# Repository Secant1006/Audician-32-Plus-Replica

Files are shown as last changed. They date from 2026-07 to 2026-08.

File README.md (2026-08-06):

# Audician 32 Plus Replica

This is a reverse-engineered sound card based on [Labway A151-A00](https://theretroweb.com/expansioncards/s/labway-corporation-labsound-a00-ide-power-a), which is a Yamaha OPL3-SAx based sound card. The OPL3-SAx is a single solution sound chip which provides Sound Blaster Pro 2.0 and Windows Sound System compatibility, and more importantly, a genuine OPL3 FM synthesizer. It's almost perfect (except ADPCM support) for PC-based retro gaming. Besides outstanding compatibility, this card is also noise-free and has acceptable frequency response.

As of August 2026, no one has published any schematic for this chip yet. This project aims to provide a reverse-engineered schematic and nearly 1:1 clone of the A151-A00 sound card with some modifications:

* Wavetable reverse channel bug is fixed
* Original FCC ID and CE logo are not used
* Silkscreen font is different
* Footprints are replaced with KiCad defaults plus some self-made ones
* Silkscreens for chip model are corrected
* Board is slightly longer and the ISA connector is moved slightly to comply with ISA standard

One configuration of the board is manufactured and validated to work perfectly fine.

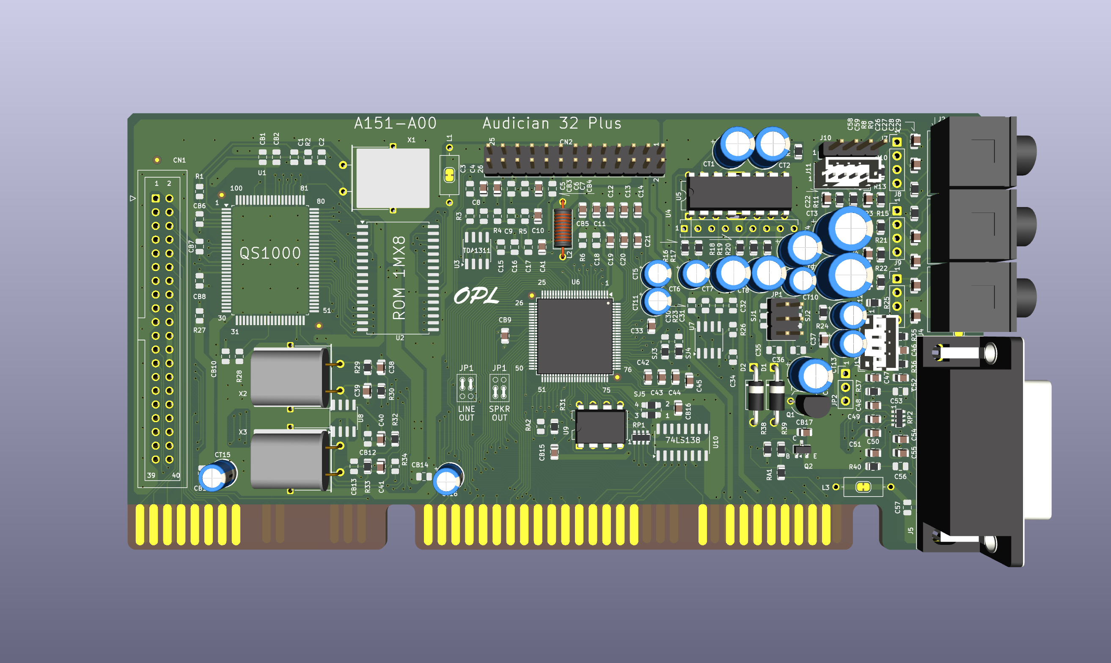
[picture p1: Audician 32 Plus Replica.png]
PCB Rendering


# Project Structure

* `bom/`: Interactive BOM
* `eeprom/`: EEPROM dump
* `gerber/`: Gerber files for the PCB
* `jlcpcb/`: JLCPCB production files
* `references/`: Reference documents, including datasheets for chips, ISA standard specification and photos of the original PCB
* Others: KiCad project files

# BOM

| References | Value | LCSC Part Number |
| --- | --- | --- |
| C4, C7 | 150pF 0805 | C1716 |
| C5, C10 | 220nF 0805 | C5378 |
| C11<sup>[1]</sup>, C12<sup>[1]</sup>, C19<sup>[1]</sup>, C20<sup>[1]</sup>, C44, C45 | 1nF 0805 | C46653 |
| C13, C21, C48, C49, C50, C51 | 10nF 0805 | C1710 |
| C14, C33, C37, CB5, CB9, CB15, CB16, CB17 | 100nF 0805 | C49678 |
| C22, C23, C24, C25, C28, C42, C43, C46 | 1uF 0805 | C28323 |
| C26, C27 | 470pF 0805 | C1743 |
| C29, CA1 | 100pF 0805 | C1790 |
| C38<sup>[2]</sup>, C39<sup>[2]</sup> | 4.7pF 0805 | C1820 |
| C40, C41 | 22pF 0805 | C1804 |
| C47, C52, C54, C55, C58, C59 | 47pF 0805 | C14857 |
| CT1, CT2, CT4, CT7, CT8 | 100uF D6.3xL7 | C106447 |
| CT3, CT10 | 470uF D8xL11 | C106735 |
| CT5, CT11 | 22uF D5xL7 | C112508 |
| CT6, CT9, CT12, CT13, CT15, CT16 | 10uF D4xL7 | C5123345 |
| CT14 | 100uF D6.3xL7 | C2826426 |
| R7, R18 | 510Ω 0805 | C17734 |
| R8, R9 | 47kΩ 0805 | C17713 |
| R10, R11, R12, R13 | 20kΩ 0805 | C4328 |
| R14, R21, R35 | 220kΩ 0805 | C17556 |
| R15, R22, R36 | 33kΩ 0805 | C17633 |
| R16, R17, R19, R20 | 27kΩ 0805 | C17593 |
| R24, R25 | 7.5kΩ 0805 | C17807 |
| R29<sup>[2]</sup> | 3.9kΩ 0805 | C17614 |
| R30, R32 | 75Ω 0805 | C20638 |
| R31 | 0Ω 0805 | C17477 |
| R33 | 1MΩ 0805 | C17514 |
| R37, R38, R39, R40 | 2.2kΩ 0805 | C17520 |
| RA1 | 150Ω | C17471 |
| RP1<sup>[3]</sup> | 0Ω 0603x4 | C52175182 |
| RP2 | 2.2kΩ 0603x4 | C52175185 |
| SJ3<sup>[4]</sup>, SJ4<sup>[4]</sup> | 0Ω 0805 | C17477 |
| SJ5<sup>[3]</sup> | 0Ω 0805<br>10kΩ 0805  | C17477<br>C17414 |
| D1, D2 | 1N4001 DO-41 | C2456 |
| L2 | Axial D3.5xL4.7 | C192456 |
| Q1 | 78L05 TO-92 | C8608 |
| Q2 | MMBT3904 SOT-23 | C364310 |
| U5 | TEA2025B DIP-16 | C434515 |
| U6<sup>[5]</sup> | OPL3-SAx LQFP-100 | |
| U9<sup>[3]</sup> | 93C66 DIP-8 | C434597 |
| U10<sup>[3]</sup> | 74LS138D | C7736 |
| X2<sup>[2]</sup> | 33.8688MHz HC-49U | |
| X3 | 24.576MHz HC-49U | |
| CN1<sup>[3]</sup> | 2x20pin Dupont 2.54mm | C5224014 |
| CN2 | 2x13pin Dupont 2.54mm | C41430886 |
| J2, J3, J4 | PJ-317 | C381121 |
| J5 | DB-15 Female | C77835 |
| J10 | 1x4pin Dupont 2.54mm  | C2691448 |
| J11, J13 | 1x4pin JST PH2.0 | C722763 |
| JP1 | 2x3pin Dupont 2.54mm  | C492420 |

Notes:

1. [Low-Pass Filter Mod](https://www.vogons.org/viewtopic.php?p=527947#p527947): This is a mod for this card to make Sound Blaster effects sound more like a real Sound Blaster Pro 2.0. If you want to perform this mod, replace the two SBFLT caps with 6.8nF (LCSC part number C1755). For YMF711/718, the SBFLT caps are C12 and C20. For YMF715/719/741, the SBFLT caps are C11 and C19.
1. C38, C39, R29, X2: If using a 3rd overtone crystal, which most probably is for 33.8688MHz in HC-49U package, then go with the values above. If using a fundamental crystal, then replace C38, C39 and R29 according to the crystal's datasheet. If the card doesn't work correctly then I suggest measuring the crystal output with an oscilloscope.
1. RP1, SJ5, U9, U10, CN1: If you want to use the CD-ROM interface on the sound card, do **NOT** install RP1, install a 10kΩ resistor in SJ5's 1-2 position and a 0Ω in 3-4. Otherwise, install RP1, a 10kΩ resistor in SJ5's **1-3** position and a 0Ω in **2-4**, and do not install U10 and CN1. Then flash the EEPROM (U9) with a programmer. EEPROM images are in the `eeprom/` folder.
1. SJ3, SJ4: Install two 0Ω resistors in 2-3 position.
1. U6: This card supports YMF711 (OPL3-SA2), YMF718 (OPL3-SA2C), YMF715 (OPL3-SA3), YMF719 (OPL3-SA3C) and YMF741 (OPL3-SA3L) in LQFP-100 package. Note that YMF715**F**-S may not work correctly according to some report.

The BOM for the onboard QS1000 wavetable is not listed. Some components, like U7 and some capacitors / resistors, are not present on any variant of this card. I have no idea on what values they are.

As of August 2026, all of the components except the OPL3-SAx chip are still being manufactured. The crystals are not sold by LCSC but they can be sourced through other channels.

# Bracket

The replica should be compatible with the original bracket if the connectors are installed correctly. A model for 3D-printing will be available in the future.

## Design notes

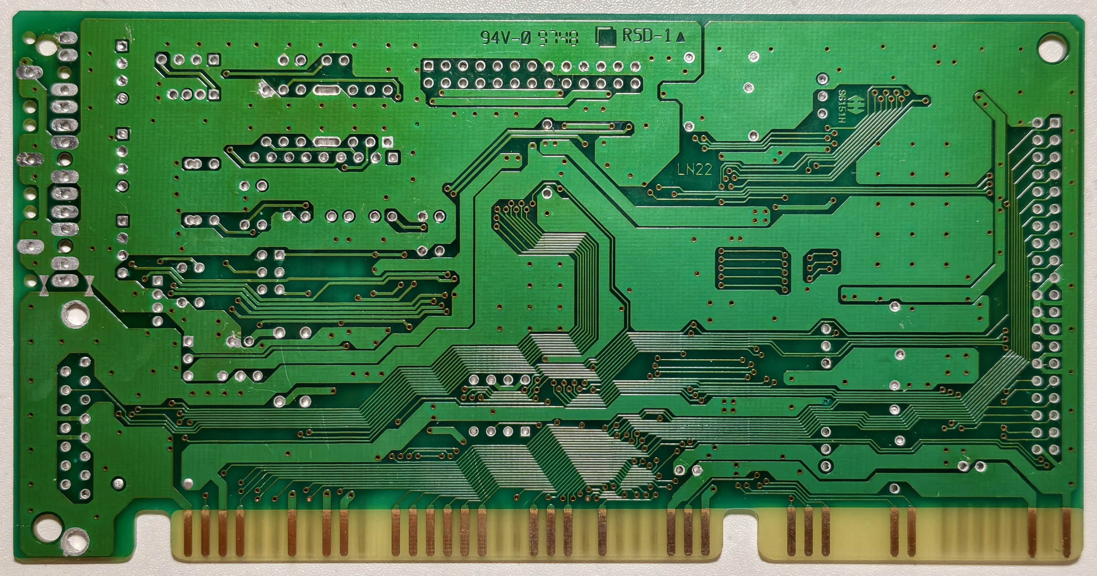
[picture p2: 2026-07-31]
references/PCB bottom.jpg

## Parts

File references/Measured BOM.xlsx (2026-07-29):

C10 | 213nF?
C11 | 1nF
C12 | 1nF
C13 | 8nF?
C14 | 100nF
C19 | 1nF
C20 | 1nF
C21 | 9nF?
C22 | 800nF?
C23 | 700nF?
C24 | 600nF?
C25 | 1uF
C26 | 470pF
C27 | 470pF
C28 | 800nF?
C29 | 96pF?
C33 | 100nF
C37 | 100nF
C38 | 4pF?
C39 | 4pF?
C4 | 142pF?
C40 | 19pF?
C41 | 19pF?
C42 | 1uF
C43 | 1uF
C44 | 1nF
C45 | 1nF
C46 | 800nF?
C47 | 47pF
C48 | 8nF?
C49 | 8nF?
C5 | 200nF
C50 | 8nF?
C51 | 8nF?
C52 | 47pF
C54 | 47pF
C55 | 47pF
C58 | 43pF?
C59 | 42pF?
C7 | 142pF?
CA1 | 100pF
CB15 | 100nF
CB16 | 100nF
CB17 | 100nF
CB5 | 100nF
CB9 | 100nF
R10 | 20kΩ
R11 | 20kΩ
R12 | 20kΩ
R13 | 20kΩ
R14 | 220kΩ
R15 | 33kΩ
R16 | 27kΩ
R17 | 27kΩ
R18 | 510Ω
R19 | 27kΩ
R20 | 27kΩ
R21 | 220kΩ
R22 | 33kΩ
R24 | 7.5kΩ
R25 | 7.5kΩ
R29 | 3.9kΩ
R30 | 75Ω
R31 | 0Ω
R32 | 75Ω
R33 | 1MΩ
R35 | 220kΩ
R36 | 33kΩ
R37 | 2.2kΩ
R38 | 2.2kΩ
R39 | 2.2kΩ
R40 | 2.2kΩ
R7 | 510Ω
R8 | 47kΩ
R9 | 47kΩ
RA1 | 150Ω
RP1 | 0Ω
RP2 | 2.2kΩ
SJ3 | 2-3
SJ4 | 2-3
SJ5 | NoCD: 2-4 0Ω, 1-3 10kΩ; CD: 3-4 0Ω, 1-2 10kΩ

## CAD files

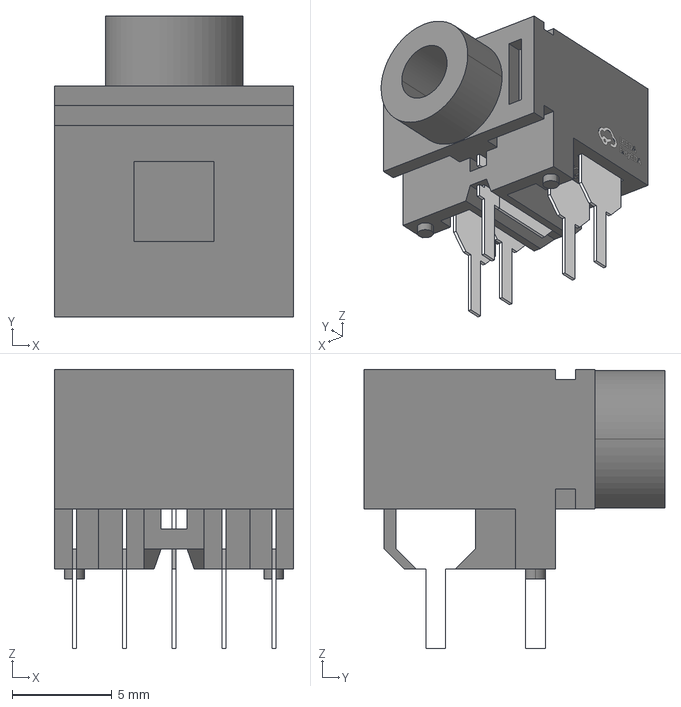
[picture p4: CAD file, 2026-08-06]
models/AUDIO-TH_3PIN_PJ-317-B.step
12.0 x 15.1 x 14.0 mm

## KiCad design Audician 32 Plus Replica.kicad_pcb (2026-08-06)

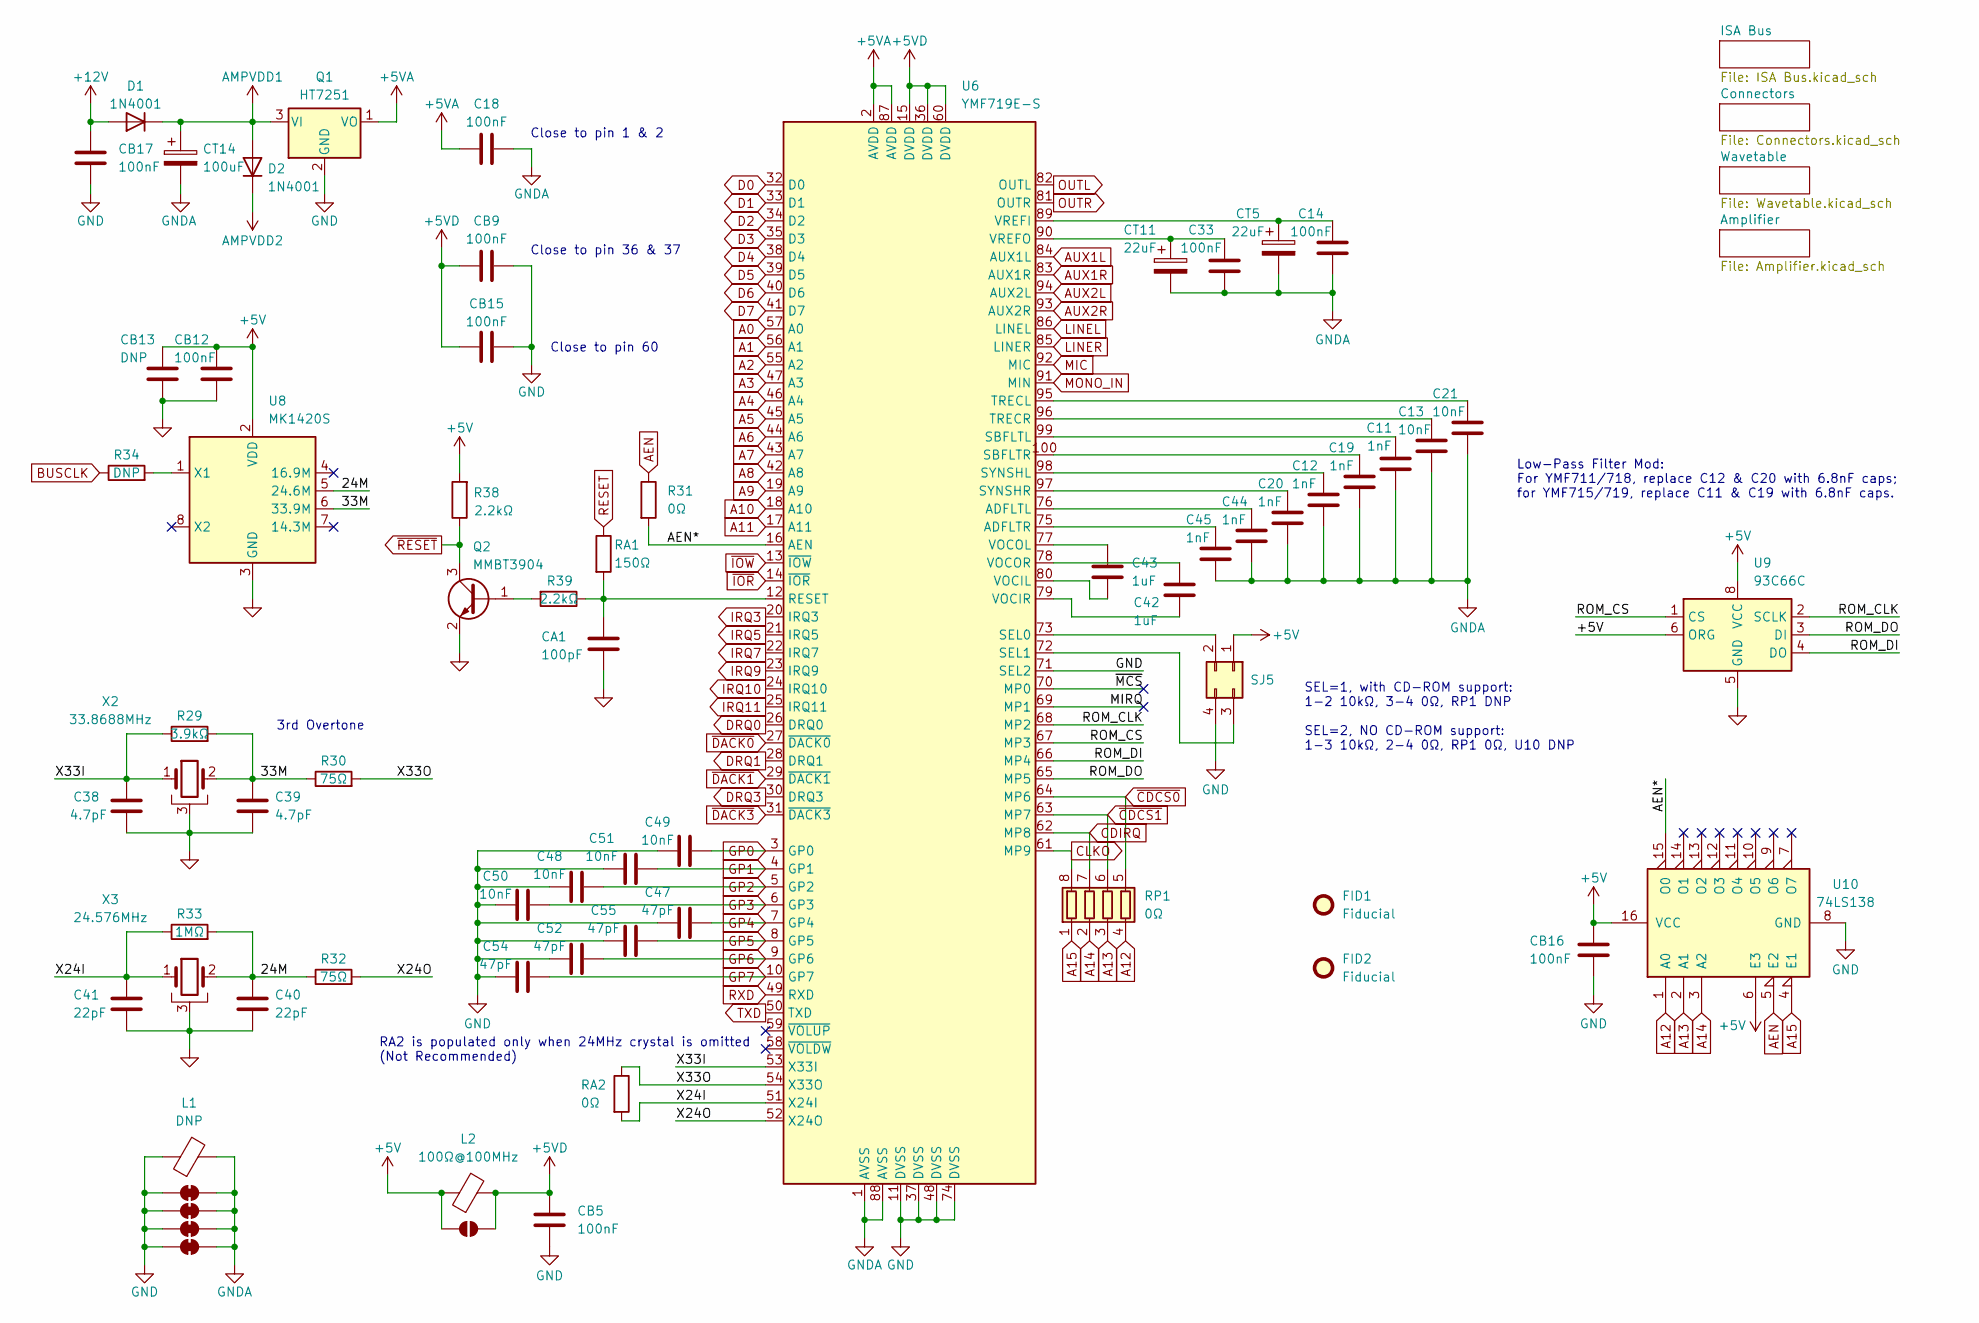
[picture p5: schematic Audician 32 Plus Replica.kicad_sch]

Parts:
C11, C19: 1nF; C_0805_2012Metric; LCSC C1755
C12, C20, C44, C45: 1nF; C_0805_2012Metric; LCSC C46653
C13, C21, C48, C49, C50, C51: 10nF; C_0805_2012Metric; LCSC C1710
C14, C33: 100nF; C_0805_2012Metric; LCSC C49678
C18: 100nF; C_0805_2012Metric
C38, C39: 4.7pF; C_0805_2012Metric; LCSC C1820
C40, C41: 22pF; C_0805_2012Metric; LCSC C1804
C42, C43: 1uF; C_0805_2012Metric; LCSC C28323
C47, C52, C54, C55: 47pF; C_0805_2012Metric; LCSC C14857
CA1: 100pF; C_0805_2012Metric; LCSC C1790
CB5, CB9, CB15, CB16, CB17: 100nF; C_0805_2012Metric; LCSC C49678
CB12: 100nF; C_0805_2012Metric
CB13: DNP; C_0805_2012Metric
CT5, CT11: 22uF; CP_Radial_D5.0mm_P2.50mm; LCSC C112508
CT14: 100uF; CP_Radial_D6.3mm_P2.50mm; LCSC C2826426
D1, D2: 1N4001; D_DO-41_SOD81_P10.16mm_Horizontal; LCSC C2456
FID1, FID2: Fiducial; Fiducial_0.75mm_Mask1.5mm
L1: DNP; L_Axial_L7.0mm_D3.3mm_P10.16mm_Horizontal_Fastron_MICC
L2: 100Ω@100MHz; L_Axial_L7.0mm_D3.3mm_P10.16mm_Horizontal_Fastron_MICC; LCSC C192456
Q1: HT7251; TO-92_Inline_Wide; LCSC C5355526
Q2: MMBT3904; SOT-23; LCSC C364310
R29: 3.9kΩ; R_0805_2012Metric; LCSC C17614
R30, R32: 75Ω; R_0805_2012Metric; LCSC C20638
R31: 0Ω; R_0805_2012Metric; LCSC C17477
R33: 1MΩ; R_0805_2012Metric; LCSC C17514
R34: DNP; R_0805_2012Metric
R38, R39: 2.2kΩ; R_0805_2012Metric; LCSC C17520
RA1: 150Ω; R_0805_2012Metric; LCSC C17471
RA2: 0Ω; R_0805_2012Metric
RP1: 0Ω; R_Array_Convex_4x0603; LCSC C52175182
SJ5: Conn_02x02; SolderJumper_02x02_0805; LCSC C17414
SJL1, SJL4, SJL5, SJL6: SolderJumper_2_Bridged; SolderJumper-2_P1.3mm_Bridged_RoundedPad1.0x1.5mm
SJL2: SolderJumper_2_Open; SolderJumper-2_P1.3mm_Open_RoundedPad1.0x1.5mm
U6: YMF719E-S; LQFP-100_14x14mm_P0.5mm
U8: MK1420S; SOIC-8_3.9x4.9mm_P1.27mm
U9: 93C66C; DIP-8_W7.62mm; LCSC C434597
U10: 74LS138; SOIC-16_3.9x9.9mm_P1.27mm
X2: 33.8688MHz; Crystal_HC49-U_Horizontal_1EP_style2
X3: 24.576MHz; Crystal_HC49-U_Horizontal_1EP_style2

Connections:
+5V: CB12.1, CB13.1, CB16.1, L2.1, R38.2, SJ5.1, SJL2.1 (A), U8.2 (VDD), U9.6 (ORG), U9.8 (VCC), U10.6 (E3), U10.16 (VCC); also elsewhere on the board
+5VA: C18.1, Q1.1 (VO), U6.2 (AVDD), U6.87 (AVDD); also elsewhere on the board
+5VD: CB5.2, CB9.1, CB15.1, L2.2, SJL2.2 (B), U6.15 (DVDD), U6.36 (DVDD), U6.60 (DVDD)
+12V: CB17.1, D1.2 (A); also elsewhere on the board
/24M: C40.1, R32.1, R33.2, U8.5 (24.6M), X3.2
/33M: C39.1, R29.2, R30.1, U8.6 (33.9M), X2.2
/AEN*: R31.2, U6.16 (AEN), U10.15 (O0)
/MIRQ: U6.69 (MP1)
/ROM_CLK: U6.68 (MP2), U9.2 (SCLK)
/ROM_CS: U6.67 (MP3), U9.1 (CS)
/ROM_DI: U6.66 (MP4), U9.4 (DO)
/ROM_DO: U6.65 (MP5), U9.3 (DI)
/X24I: C41.1, R33.1, RA2.2, U6.51 (X24I), X3.1
/X24O: R32.2, U6.52 (X24O)
/X33I: C38.1, R29.1, U6.53 (X33I), X2.1
/X33O: R30.2, RA2.1, U6.54 (X33O)
/~MCS: U6.70 (MP0)
A0: U6.57 (A0); also elsewhere on the board
A1: U6.56 (A1); also elsewhere on the board
A2: U6.55 (A2); also elsewhere on the board
A3: U6.47 (A3); also elsewhere on the board
A4: U6.46 (A4); also elsewhere on the board
A5: U6.45 (A5); also elsewhere on the board
A6: U6.44 (A6); also elsewhere on the board
A7: U6.43 (A7); also elsewhere on the board
A8: U6.42 (A8); also elsewhere on the board
A9: U6.19 (A9); also elsewhere on the board
A10: U6.18 (A10); also elsewhere on the board
A11: U6.17 (A11); also elsewhere on the board
A12: RP1.4 (R4.1), U10.1 (A0); also elsewhere on the board
A13: RP1.3 (R3.1), U10.2 (A1); also elsewhere on the board
A14: RP1.2 (R2.1), U10.3 (A2); also elsewhere on the board
A15: RP1.1 (R1.1), U10.4 (E1); also elsewhere on the board
AEN: R31.1, U10.5 (E2); also elsewhere on the board
AMPVDD1: CT14.1, D1.1 (K), D2.2 (A), Q1.3 (VI); also elsewhere on the board
AMPVDD2: D2.1 (K); also elsewhere on the board
AUX1L: U6.84 (AUX1L); also elsewhere on the board
AUX1R: U6.83 (AUX1R); also elsewhere on the board
AUX2L: U6.94 (AUX2L); also elsewhere on the board
AUX2R: U6.93 (AUX2R); also elsewhere on the board
BUSCLK: R34.1; also elsewhere on the board
CDIRQ: RP1.7 (R2.2), U6.62 (MP8); also elsewhere on the board
CLKO: RP1.8 (R1.2), U6.61 (MP9)
D0: U6.32 (D0); also elsewhere on the board
D1: U6.33 (D1); also elsewhere on the board
D2: U6.34 (D2); also elsewhere on the board
D3: U6.35 (D3); also elsewhere on the board
D4: U6.38 (D4); also elsewhere on the board
D5: U6.39 (D5); also elsewhere on the board
D6: U6.40 (D6); also elsewhere on the board
D7: U6.41 (D7); also elsewhere on the board
DRQ0: U6.26 (DRQ0); also elsewhere on the board
DRQ1: U6.28 (DRQ1); also elsewhere on the board
DRQ3: U6.30 (DRQ3); also elsewhere on the board
GND: C38.2, C39.2, C40.2, C41.2, C47.1, C48.1, C49.1, C50.1, C51.1, C52.1, C54.1, C55.1, CA1.2, CB5.1, CB9.2, CB12.2, CB13.2, CB15.2, CB16.2, CB17.2, L1.1, Q1.2 (GND), Q2.2 (E), SJ5.4, SJL1.1 (A), SJL4.1 (A), SJL5.1 (A), SJL6.1 (A), U6.11 (DVSS), U6.37 (DVSS), U6.48 (DVSS), U6.71 (SEL2), U6.74 (DVSS), U8.3 (GND), U9.5 (GND), U10.8 (GND), X2.3, X3.3; also elsewhere on the board
GNDA: C11.1, C12.1, C13.1, C14.2, C18.2, C19.1, C20.1, C21.1, C33.1, C44.1, C45.1, CT5.2, CT11.2, CT14.2, L1.2, SJL1.2 (B), SJL4.2 (B), SJL5.2 (B), SJL6.2 (B), U6.1 (AVSS), U6.88 (AVSS); also elsewhere on the board
GP0: C49.2, U6.3 (GP0); also elsewhere on the board
GP1: C51.2, U6.4 (GP1); also elsewhere on the board
GP2: C48.2, U6.5 (GP2); also elsewhere on the board
GP3: C50.2, U6.6 (GP3); also elsewhere on the board
GP4: C47.2, U6.7 (GP4); also elsewhere on the board
GP5: C55.2, U6.8 (GP5); also elsewhere on the board
GP6: C52.2, U6.9 (GP6); also elsewhere on the board
GP7: C54.2, U6.10 (GP7); also elsewhere on the board
IRQ3: U6.20 (IRQ3); also elsewhere on the board
IRQ5: U6.21 (IRQ5); also elsewhere on the board
IRQ7: U6.22 (IRQ7); also elsewhere on the board
IRQ9: U6.23 (IRQ9); also elsewhere on the board
IRQ10: U6.24 (IRQ10); also elsewhere on the board
IRQ11: U6.25 (IRQ11); also elsewhere on the board
LINEL: U6.86 (LINEL); also elsewhere on the board
LINER: U6.85 (LINER); also elsewhere on the board
MIC: U6.92 (MIC); also elsewhere on the board
MONO_IN: U6.91 (MIN); also elsewhere on the board
unnamed: Q2.1 (B), R39.2
unnamed: SJ5.2, U6.73 (SEL0)
unnamed: SJ5.3, U6.72 (SEL1)
unnamed: C44.2, U6.76 (ADFLTL)
unnamed: C45.2, U6.75 (ADFLTR)
unnamed: CA1.1, R39.1, RA1.2, U6.12 (RESET)
unnamed: C11.2, U6.99 (SBFLTL)
unnamed: C19.2, U6.100 (SBFLTR)
unnamed: C12.2, U6.98 (SYNSHL)
unnamed: C20.2, U6.97 (SYNSHR)
unnamed: C21.2, U6.95 (TRECL)
unnamed: C13.2, U6.96 (TRECR)
unnamed: C43.2, U6.80 (VOCIL)
unnamed: C42.2, U6.79 (VOCIR)
unnamed: C43.1, U6.77 (VOCOL)
unnamed: C42.1, U6.78 (VOCOR)
unnamed: C14.1, CT5.1, U6.89 (VREFI)
unnamed: C33.2, CT11.1, U6.90 (VREFO)
unnamed: R34.2, U8.1 (X1)
OUTL: U6.82 (OUTL); also elsewhere on the board
OUTR: U6.81 (OUTR); also elsewhere on the board
RESET: RA1.1; also elsewhere on the board
RXD: U6.49 (RXD); also elsewhere on the board
TXD: U6.50 (TXD); also elsewhere on the board
~CDCS0: RP1.5 (R4.2), U6.64 (MP6); also elsewhere on the board
~CDCS1: RP1.6 (R3.2), U6.63 (MP7); also elsewhere on the board
~DACK0: U6.27 (~DACK0); also elsewhere on the board
~DACK1: U6.29 (~DACK1); also elsewhere on the board
~DACK3: U6.31 (~DACK3); also elsewhere on the board
~IOR: U6.14 (~IOR); also elsewhere on the board
~IOW: U6.13 (~IOW); also elsewhere on the board
~RESET: Q2.3 (C), R38.1; also elsewhere on the board

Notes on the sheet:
SEL=1, with CD-ROM support: 1-2 10kΩ, 3-4 0Ω, RP1 DNP SEL=2, NO CD-ROM support: 1-3 10kΩ, 2-4 0Ω, RP1 0Ω, U10 DNP
Close to pin 1 & 2
Low-Pass Filter Mod: For YMF711/718, replace C12 & C20 with 6.8nF caps; for YMF715/719, replace C11 & C19 with 6.8nF caps.
Close to pin 36 & 37
3rd Overtone
Close to pin 60
RA2 is populated only when 24MHz crystal is omitted (Not Recommended)

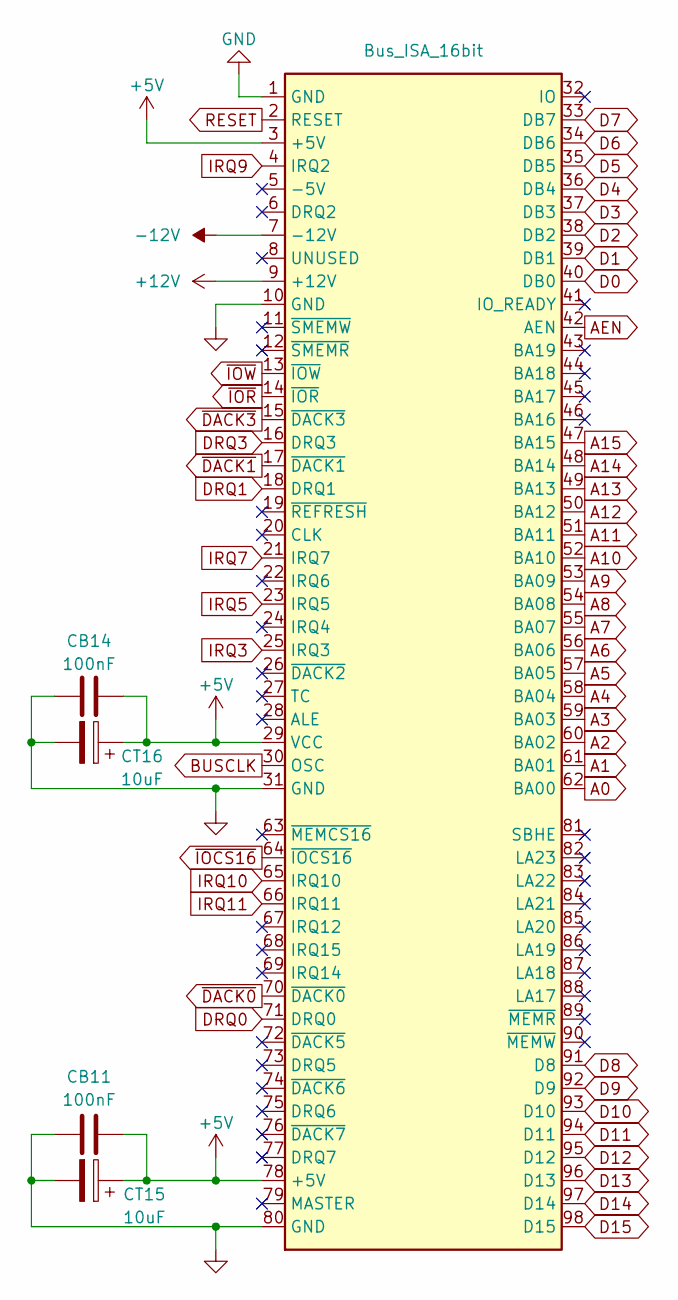
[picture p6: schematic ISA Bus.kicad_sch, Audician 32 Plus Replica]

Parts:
CB11, CB14: 100nF; C_0805_2012Metric
CT15, CT16: 10uF; CP_Radial_D5.0mm_P2.50mm; LCSC C5123345
J1: Bus_ISA_16bit; BUS_AT

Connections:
+5V: CB11.2, CB14.2, CT15.1, CT16.1, J1.3 (+5V), J1.29 (VCC), J1.78 (+5V); also elsewhere on the board
+12V: J1.9 (+12V); also elsewhere on the board
-12V: J1.7 (-12V); also elsewhere on the board
A0: J1.62 (BA00); also elsewhere on the board
A1: J1.61 (BA01); also elsewhere on the board
A2: J1.60 (BA02); also elsewhere on the board
A3: J1.59 (BA03); also elsewhere on the board
A4: J1.58 (BA04); also elsewhere on the board
A5: J1.57 (BA05); also elsewhere on the board
A6: J1.56 (BA06); also elsewhere on the board
A7: J1.55 (BA07); also elsewhere on the board
A8: J1.54 (BA08); also elsewhere on the board
A9: J1.53 (BA09); also elsewhere on the board
A10: J1.52 (BA10); also elsewhere on the board
A11: J1.51 (BA11); also elsewhere on the board
A12: J1.50 (BA12); also elsewhere on the board
A13: J1.49 (BA13); also elsewhere on the board
A14: J1.48 (BA14); also elsewhere on the board
A15: J1.47 (BA15); also elsewhere on the board
AEN: J1.42 (AEN); also elsewhere on the board
BUSCLK: J1.30 (OSC); also elsewhere on the board
D0: J1.40 (DB0); also elsewhere on the board
D1: J1.39 (DB1); also elsewhere on the board
D2: J1.38 (DB2); also elsewhere on the board
D3: J1.37 (DB3); also elsewhere on the board
D4: J1.36 (DB4); also elsewhere on the board
D5: J1.35 (DB5); also elsewhere on the board
D6: J1.34 (DB6); also elsewhere on the board
D7: J1.33 (DB7); also elsewhere on the board
D8: J1.91 (D8); also elsewhere on the board
D9: J1.92 (D9); also elsewhere on the board
D10: J1.93 (D10); also elsewhere on the board
D11: J1.94 (D11); also elsewhere on the board
D12: J1.95 (D12); also elsewhere on the board
D13: J1.96 (D13); also elsewhere on the board
D14: J1.97 (D14); also elsewhere on the board
D15: J1.98 (D15); also elsewhere on the board
DRQ0: J1.71 (DRQ0); also elsewhere on the board
DRQ1: J1.18 (DRQ1); also elsewhere on the board
DRQ3: J1.16 (DRQ3); also elsewhere on the board
GND: CB11.1, CB14.1, CT15.2, CT16.2, J1.1 (GND), J1.10 (GND), J1.31 (GND), J1.80 (GND); also elsewhere on the board
IRQ3: J1.25 (IRQ3); also elsewhere on the board
IRQ5: J1.23 (IRQ5); also elsewhere on the board
IRQ7: J1.21 (IRQ7); also elsewhere on the board
IRQ9: J1.4 (IRQ2); also elsewhere on the board
IRQ10: J1.65 (IRQ10); also elsewhere on the board
IRQ11: J1.66 (IRQ11); also elsewhere on the board
RESET: J1.2 (RESET); also elsewhere on the board
~DACK0: J1.70 (~DACK0); also elsewhere on the board
~DACK1: J1.17 (~DACK1); also elsewhere on the board
~DACK3: J1.15 (~DACK3); also elsewhere on the board
~IOCS16: J1.64 (~IOCS16); also elsewhere on the board
~IOR: J1.14 (~IOR); also elsewhere on the board
~IOW: J1.13 (~IOW); also elsewhere on the board

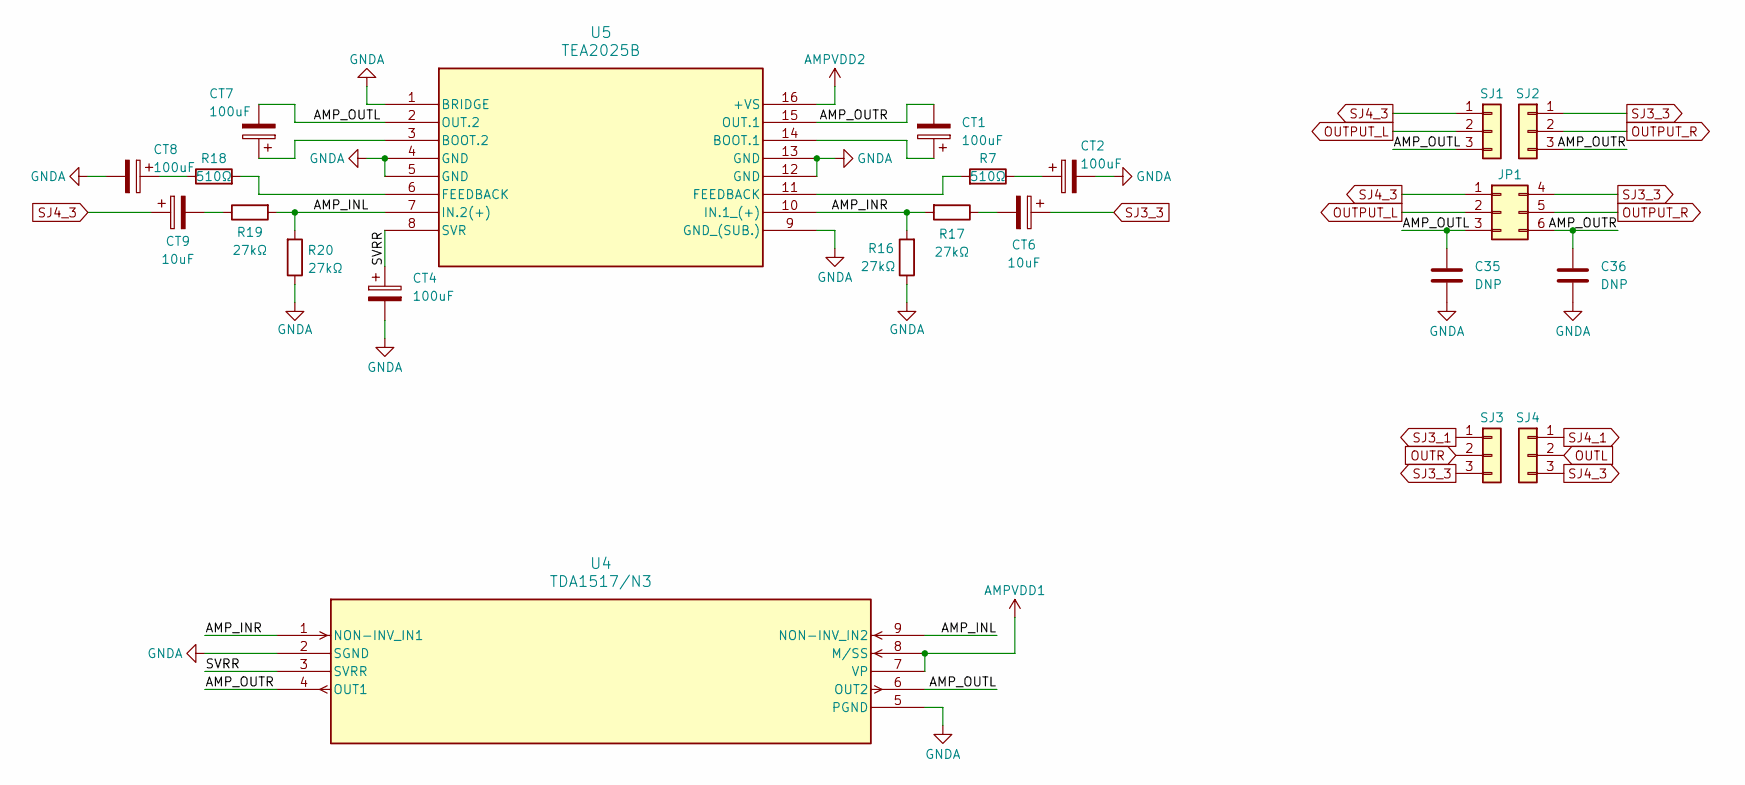
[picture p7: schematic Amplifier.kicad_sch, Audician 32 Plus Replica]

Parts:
C35, C36: DNP; C_0805_2012Metric
CT1, CT2, CT4, CT7, CT8: 100uF; CP_Radial_D6.3mm_P2.50mm; LCSC C106447
CT6, CT9: 10uF; CP_Radial_D5.0mm_P2.50mm; LCSC C5123345
JP1: Conn_02x03_Top_Bottom; PinHeader_2x03_P2.54mm_Vertical; LCSC C492420
R7, R18: 510Ω; R_0805_2012Metric; LCSC C17734
R16, R17, R19, R20: 27kΩ; R_0805_2012Metric; LCSC C17593
SJ1, SJ2: Conn_01x03; SolderJumper_01x03_0805
SJ3, SJ4: Conn_01x03; SolderJumper_01x03_0805; LCSC C17477
U4: TDA1517/N3; SIP-9_21.54x3mm_P2.54mm
U5: TEA2025B; PowerDIP-16_W7.62mm; LCSC C434515

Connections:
/Amplifier/AMP_INL: R19.2, R20.2, U4.9 (NON-INV_IN2), U5.7 (IN.2(+))
/Amplifier/AMP_INR: R16.2, R17.2, U4.1 (NON-INV_IN1), U5.10 (IN.1_(+))
/Amplifier/AMP_OUTL: C35.1, CT7.2, JP1.3, SJ1.3, U4.6 (OUT2), U5.2 (OUT.2)
/Amplifier/AMP_OUTR: C36.1, CT1.2, JP1.6, SJ2.3, U4.4 (OUT1), U5.15 (OUT.1)
/Amplifier/SVRR: CT4.1, U4.3 (SVRR), U5.8 (SVR)
AMPVDD1: U4.7 (VP), U4.8 (M/SS); also elsewhere on the board
AMPVDD2: U5.16 (+VS); also elsewhere on the board
GNDA: C35.2, C36.2, CT2.2, CT4.2, CT8.2, R16.1, R20.1, U4.2 (SGND), U4.5 (PGND), U5.1 (BRIDGE), U5.4 (GND), U5.5 (GND), U5.9 (GND_(SUB.)), U5.12 (GND), U5.13 (GND); also elsewhere on the board
unnamed: CT2.1, R7.1
unnamed: CT6.2, R17.1
unnamed: CT8.1, R18.1
unnamed: CT9.2, R19.1
unnamed: R7.2, U5.11 (FEEDBACK)
unnamed: R18.2, U5.6 (FEEDBACK)
unnamed: CT1.1, U5.14 (BOOT.1)
unnamed: CT7.1, U5.3 (BOOT.2)
OUTL: SJ4.2; also elsewhere on the board
OUTPUT_L: JP1.2, SJ1.2; also elsewhere on the board
OUTPUT_R: JP1.5, SJ2.2; also elsewhere on the board
OUTR: SJ3.2; also elsewhere on the board
SJ3_1: SJ3.1; also elsewhere on the board
SJ3_3: CT6.1, JP1.4, SJ2.1, SJ3.3; also elsewhere on the board
SJ4_1: SJ4.1; also elsewhere on the board
SJ4_3: CT9.1, JP1.1, SJ1.1, SJ4.3; also elsewhere on the board

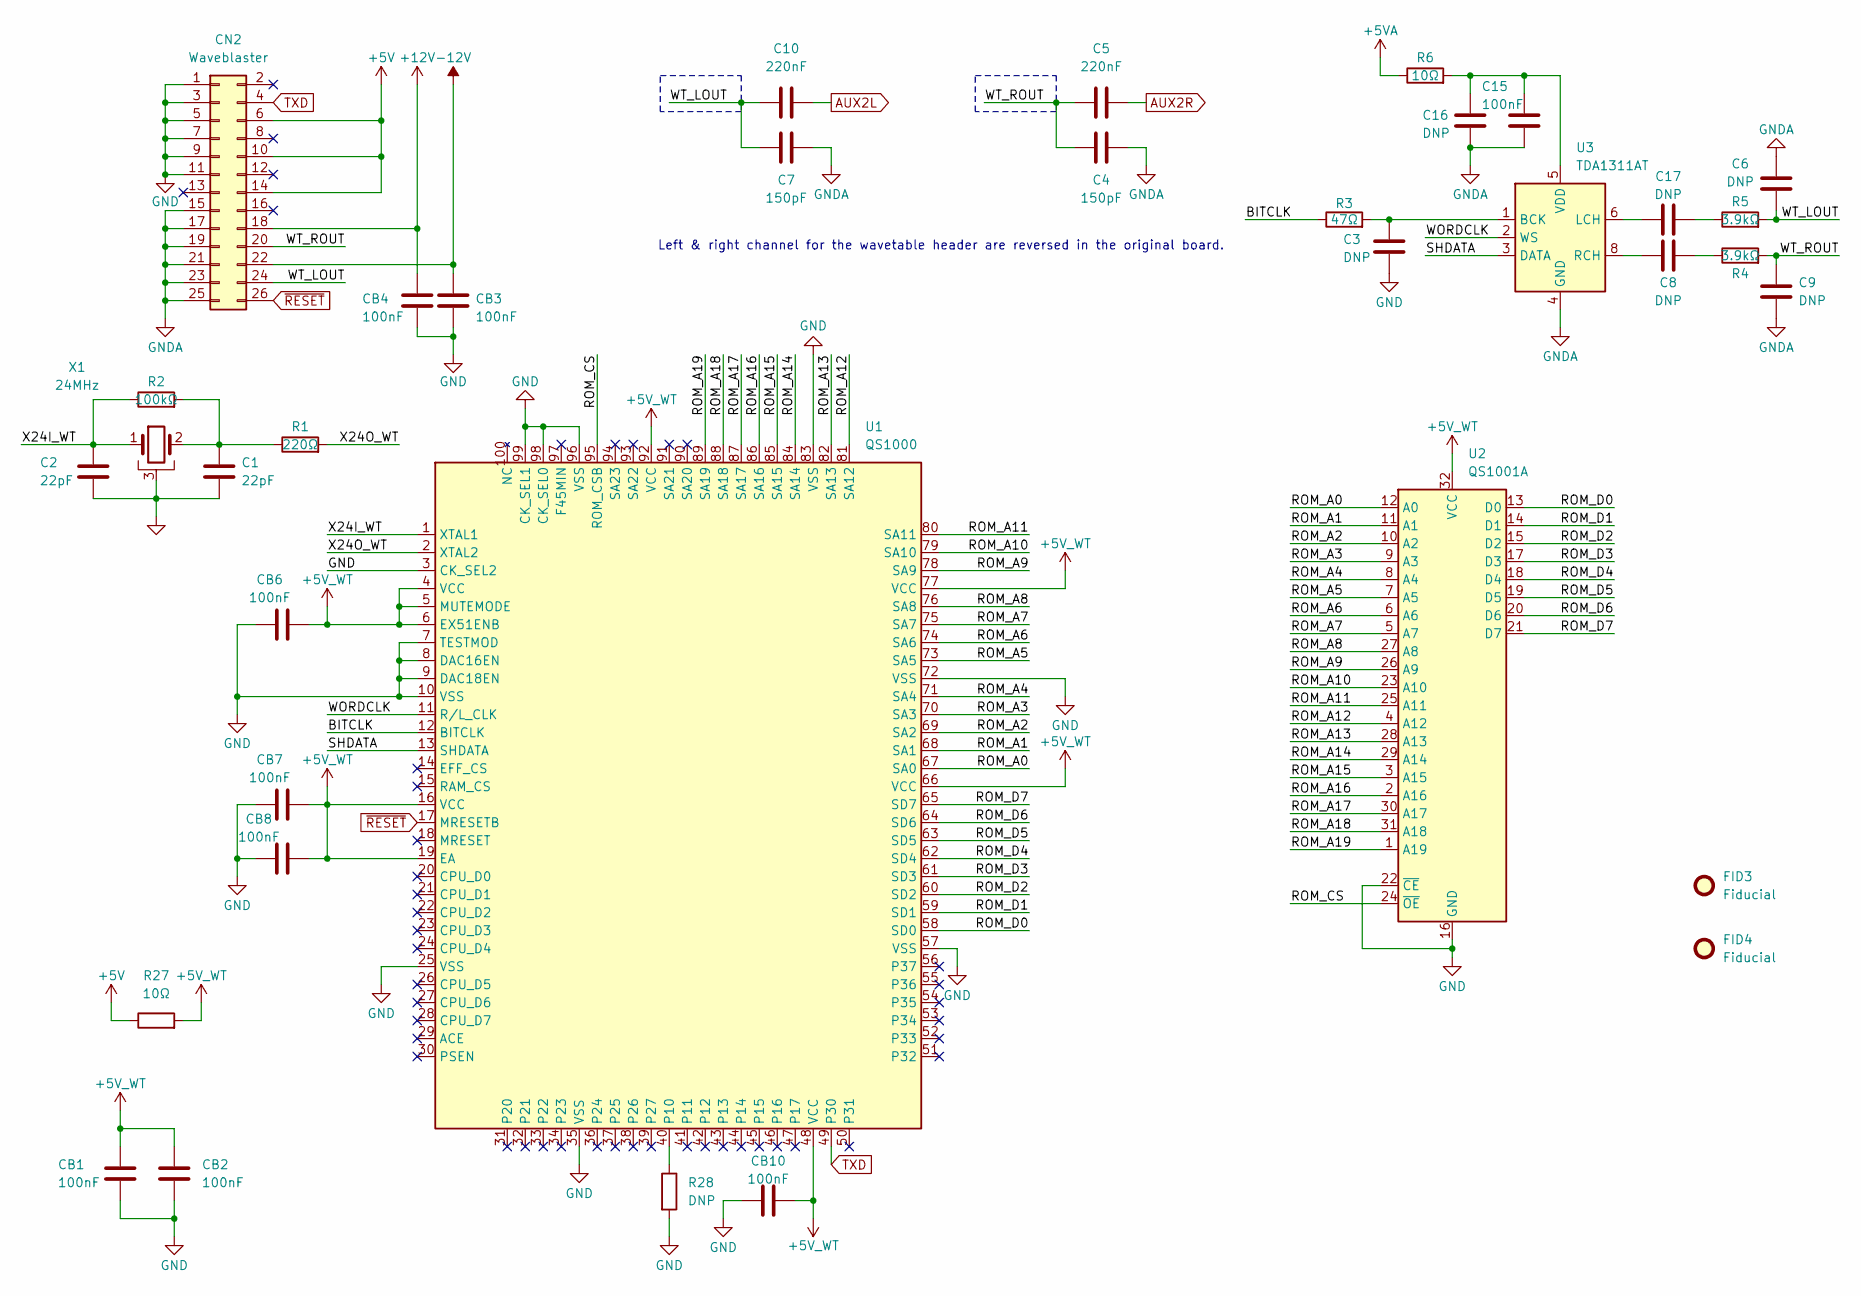
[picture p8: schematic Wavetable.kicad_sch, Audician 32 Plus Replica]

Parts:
C1, C2: 22pF; C_0805_2012Metric
C3, C6, C8, C9, C16, C17: DNP; C_0805_2012Metric
C4, C7: 150pF; C_0805_2012Metric; LCSC C1716
C5, C10: 220nF; C_0805_2012Metric; LCSC C5378
C15: 100nF; C_0805_2012Metric
CB1, CB2, CB3, CB4, CB6, CB7, CB8, CB10: 100nF; C_0805_2012Metric
CN2: Waveblaster; PinHeader_2x13_P2.54mm_Vertical; LCSC C41430886
FID3, FID4: Fiducial; Fiducial_0.75mm_Mask1.5mm
R1: 220Ω; R_0805_2012Metric
R2: 100kΩ; R_0805_2012Metric
R3: 47Ω; R_0805_2012Metric
R4, R5: 3.9kΩ; R_0805_2012Metric
R6, R27: 10Ω; R_0805_2012Metric
R28: DNP; R_0805_2012Metric
U1: QS1000; PQFP-100_14x20mm_P0.65mm
U2: QS1001A; SOP-32_11.305x20.495mm_P1.27mm
U3: TDA1311AT; SOIC-8_3.9x4.9mm_P1.27mm
X1: 24MHz; Crystal_HC49-U_Horizontal_1EP_style2

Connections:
+5V: CN2.6, CN2.10, CN2.14, R27.1; also elsewhere on the board
+5VA: R6.1; also elsewhere on the board
+5V_WT: CB1.1, CB2.1, CB6.2, CB7.2, CB8.2, CB10.2, R27.2, U1.4 (VCC), U1.5 (MUTEMODE), U1.6 (EX51ENB), U1.16 (VCC), U1.19 (EA), U1.48 (VCC), U1.66 (VCC), U1.77 (VCC), U1.92 (VCC), U2.32 (VCC)
+12V: CB4.1, CN2.18; also elsewhere on the board
-12V: CB3.1, CN2.22; also elsewhere on the board
/Wavetable/BITCLK: R3.1, U1.12 (BITCLK)
/Wavetable/ROM_A0: U1.67 (SA0), U2.12 (A0)
/Wavetable/ROM_A1: U1.68 (SA1), U2.11 (A1)
/Wavetable/ROM_A2: U1.69 (SA2), U2.10 (A2)
/Wavetable/ROM_A3: U1.70 (SA3), U2.9 (A3)
/Wavetable/ROM_A4: U1.71 (SA4), U2.8 (A4)
/Wavetable/ROM_A5: U1.73 (SA5), U2.7 (A5)
/Wavetable/ROM_A6: U1.74 (SA6), U2.6 (A6)
/Wavetable/ROM_A7: U1.75 (SA7), U2.5 (A7)
/Wavetable/ROM_A8: U1.76 (SA8), U2.27 (A8)
/Wavetable/ROM_A9: U1.78 (SA9), U2.26 (A9)
/Wavetable/ROM_A10: U1.79 (SA10), U2.23 (A10)
/Wavetable/ROM_A11: U1.80 (SA11), U2.25 (A11)
/Wavetable/ROM_A12: U1.81 (SA12), U2.4 (A12)
/Wavetable/ROM_A13: U1.82 (SA13), U2.28 (A13)
/Wavetable/ROM_A14: U1.84 (SA14), U2.29 (A14)
/Wavetable/ROM_A15: U1.85 (SA15), U2.3 (A15)
/Wavetable/ROM_A16: U1.86 (SA16), U2.2 (A16)
/Wavetable/ROM_A17: U1.87 (SA17), U2.30 (A17)
/Wavetable/ROM_A18: U1.88 (SA18), U2.31 (A18)
/Wavetable/ROM_A19: U1.89 (SA19), U2.1 (A19)
/Wavetable/ROM_CS: U1.95 (ROM_CSB), U2.24 (~OE)
/Wavetable/ROM_D0: U1.58 (SD0), U2.13 (D0)
/Wavetable/ROM_D1: U1.59 (SD1), U2.14 (D1)
/Wavetable/ROM_D2: U1.60 (SD2), U2.15 (D2)
/Wavetable/ROM_D3: U1.61 (SD3), U2.17 (D3)
/Wavetable/ROM_D4: U1.62 (SD4), U2.18 (D4)
/Wavetable/ROM_D5: U1.63 (SD5), U2.19 (D5)
/Wavetable/ROM_D6: U1.64 (SD6), U2.20 (D6)
/Wavetable/ROM_D7: U1.65 (SD7), U2.21 (D7)
/Wavetable/SHDATA: U1.13 (SHDATA), U3.3 (DATA)
/Wavetable/WORDCLK: U1.11 (R/L_CLK), U3.2 (WS)
/Wavetable/WT_LOUT: C6.1, C7.1, C10.1, CN2.24, R5.2
/Wavetable/WT_ROUT: C4.1, C5.1, C9.1, CN2.20, R4.2
/Wavetable/X24I_WT: C2.1, R2.1, U1.1 (XTAL1), X1.1
/Wavetable/X24O_WT: R1.2, U1.2 (XTAL2)
AUX2L: C10.2; also elsewhere on the board
AUX2R: C5.2; also elsewhere on the board
GND: C1.2, C2.2, C3.2, CB1.2, CB2.2, CB3.2, CB4.2, CB6.1, CB7.1, CB8.1, CB10.1, CN2.1, CN2.3, CN2.5, CN2.7, CN2.9, CN2.11, R28.2, U1.3 (CK_SEL2), U1.7 (TESTMOD), U1.8 (DAC16EN), U1.9 (DAC18EN), U1.10 (VSS), U1.25 (VSS), U1.35 (VSS), U1.57 (VSS), U1.72 (VSS), U1.83 (VSS), U1.96 (VSS), U1.98 (CK_SEL0), U1.99 (CK_SEL1), U2.16 (GND), U2.22 (~CE), X1.3; also elsewhere on the board
GNDA: C4.2, C6.2, C7.2, C9.2, C15.2, C16.2, CN2.15, CN2.17, CN2.19, CN2.21, CN2.23, CN2.25, U3.4 (GND); also elsewhere on the board
unnamed: C1.1, R1.1, R2.2, X1.2
unnamed: C8.1, R4.1
unnamed: C17.2, R5.1
unnamed: R28.1, U1.40 (P10)
unnamed: C3.1, R3.2, U3.1 (BCK)
unnamed: C17.1, U3.6 (LCH)
unnamed: C8.2, U3.8 (RCH)
unnamed: C15.1, C16.1, R6.2, U3.5 (VDD)
TXD: CN2.4, U1.49 (P30); also elsewhere on the board
~RESET: CN2.26, U1.17 (MRESETB); also elsewhere on the board

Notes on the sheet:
Left & right channel for the wavetable header are reversed in the original board.

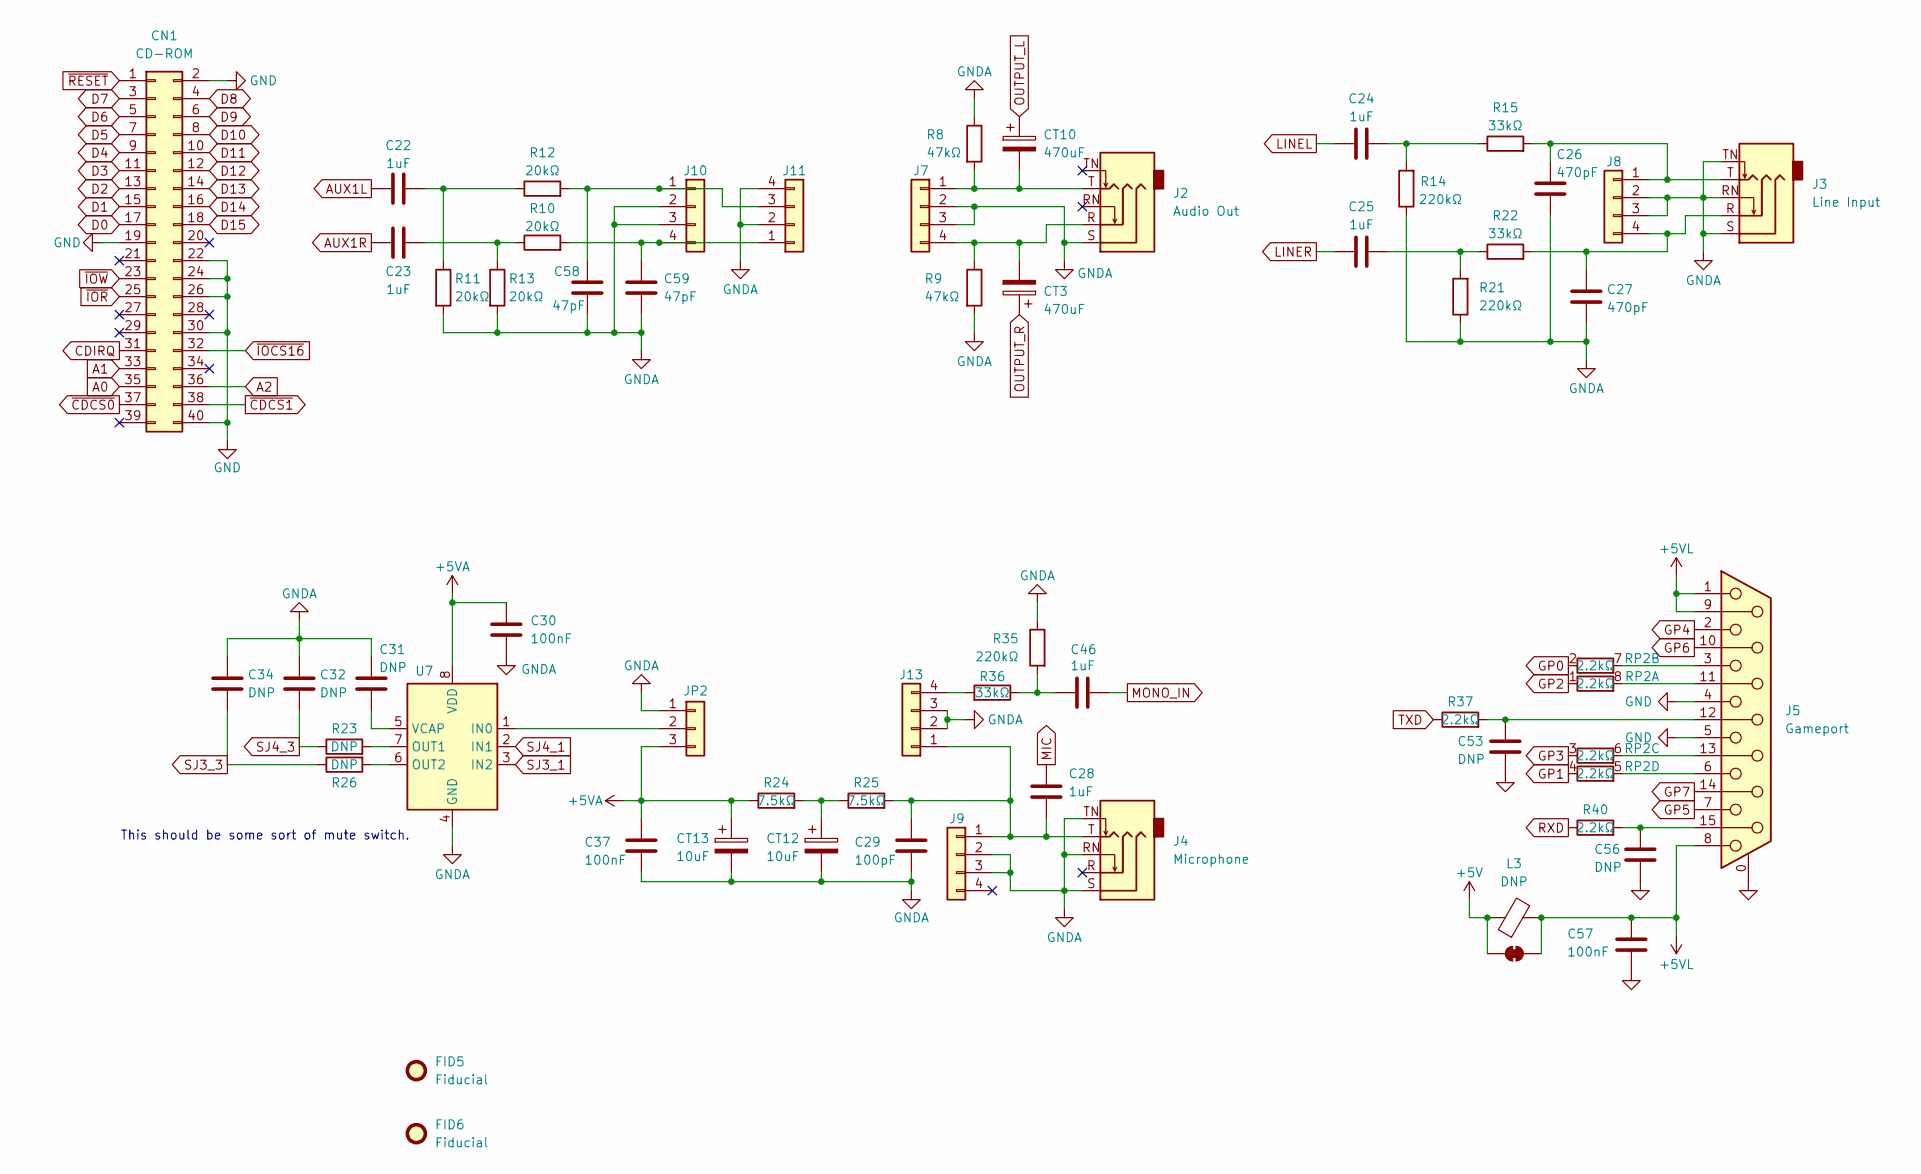
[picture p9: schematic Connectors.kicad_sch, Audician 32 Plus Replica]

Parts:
C22, C23, C24, C25, C28, C46: 1uF; C_0805_2012Metric; LCSC C28323
C26, C27: 470pF; C_0805_2012Metric; LCSC C1743
C29: 100pF; C_0805_2012Metric; LCSC C1790
C30, C57: 100nF; C_0805_2012Metric
C31, C32, C34, C53, C56: DNP; C_0805_2012Metric
C37: 100nF; C_0805_2012Metric; LCSC C49678
C58, C59: 47pF; C_0805_2012Metric; LCSC C14857
CN1: CD-ROM; IDC-Header_2x20_P2.54mm_Vertical
CT3, CT10: 470uF; CP_Radial_D8.0mm_P3.50mm; LCSC C106735
CT12, CT13: 10uF; CP_Radial_D5.0mm_P2.50mm; LCSC C5123345
FID5, FID6: Fiducial; Fiducial_0.75mm_Mask1.5mm
J2: Audio Out; Jack_3.5mm_PJ-317_Horizontal; LCSC C381121
J3: Line Input; Jack_3.5mm_PJ-317_Horizontal; LCSC C381121
J4: Microphone; Jack_3.5mm_PJ-317_Horizontal; LCSC C381121
J5: Gameport; DSUB-15_Socket_Horizontal_P2.77x2.84mm_EdgePinOffset7.70mm_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; LCSC C77835
J7, J8, J9: Conn_01x04; PinHeader_1x04_P2.54mm_Vertical
J10: Conn_01x04; PinHeader_1x04_P2.54mm_Vertical; LCSC C2691448
J11, J13: Conn_01x04; JST_PH_B4B-PH-K_1x04_P2.00mm_Vertical_Reversed; LCSC C722763
JP2: Conn_01x03; PinHeader_1x03_P2.54mm_Vertical
L3: DNP; L_Axial_L7.0mm_D3.3mm_P10.16mm_Horizontal_Fastron_MICC
R8, R9: 47kΩ; R_0805_2012Metric; LCSC C17713
R10, R11, R12, R13: 20kΩ; R_0805_2012Metric; LCSC C4328
R14, R21, R35: 220kΩ; R_0805_2012Metric; LCSC C17556
R15, R22, R36: 33kΩ; R_0805_2012Metric; LCSC C17633
R23, R26: DNP; R_0805_2012Metric
R24, R25: 7.5kΩ; R_0805_2012Metric; LCSC C17807
R37, R40: 2.2kΩ; R_0805_2012Metric; LCSC C17520
RP2: 2.2kΩ; R_Array_Convex_4x0603; LCSC C52175185
SJL3: SolderJumper_2_Bridged; SolderJumper-2_P1.3mm_Bridged_RoundedPad1.0x1.5mm
U7: Mysterious Chip; SOIC-8_3.9x4.9mm_P1.27mm

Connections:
+5V: L3.1, SJL3.1 (A); also elsewhere on the board
+5VA: C30.1, C37.1, CT13.1, JP2.3, R24.1, U7.8 (VDD); also elsewhere on the board
+5VL: C57.1, J5.1, J5.8, J5.9, L3.2, SJL3.2 (B)
A0: CN1.35; also elsewhere on the board
A1: CN1.33; also elsewhere on the board
A2: CN1.36; also elsewhere on the board
AUX1L: C22.1; also elsewhere on the board
AUX1R: C23.1; also elsewhere on the board
CDIRQ: CN1.31; also elsewhere on the board
D0: CN1.17; also elsewhere on the board
D1: CN1.15; also elsewhere on the board
D2: CN1.13; also elsewhere on the board
D3: CN1.11; also elsewhere on the board
D4: CN1.9; also elsewhere on the board
D5: CN1.7; also elsewhere on the board
D6: CN1.5; also elsewhere on the board
D7: CN1.3; also elsewhere on the board
D8: CN1.4; also elsewhere on the board
D9: CN1.6; also elsewhere on the board
D10: CN1.8; also elsewhere on the board
D11: CN1.10; also elsewhere on the board
D12: CN1.12; also elsewhere on the board
D13: CN1.14; also elsewhere on the board
D14: CN1.16; also elsewhere on the board
D15: CN1.18; also elsewhere on the board
GND: C53.2, C56.2, C57.2, CN1.2, CN1.19, CN1.22, CN1.24, CN1.26, CN1.30, CN1.40, J5.0 (PAD), J5.4, J5.5; also elsewhere on the board
GNDA: C26.2, C27.2, C29.2, C30.2, C31.1, C32.1, C34.1, C37.2, C58.2, C59.2, CT12.2, CT13.2, J2.S, J3.RN, J3.S, J3.TN, J4.RN, J4.S, J4.TN, J7.2, J7.3, J8.2, J8.3, J9.2, J9.3, J10.2, J10.3, J11.2, J11.4, J13.2, J13.3, JP2.1, R8.1, R9.2, R11.2, R13.2, R14.1, R21.1, R35.1, U7.4 (GND); also elsewhere on the board
GP0: RP2.2 (R2.1); also elsewhere on the board
GP1: RP2.4 (R4.1); also elsewhere on the board
GP2: RP2.1 (R1.1); also elsewhere on the board
GP3: RP2.3 (R3.1); also elsewhere on the board
GP4: J5.2; also elsewhere on the board
GP5: J5.7; also elsewhere on the board
GP6: J5.10; also elsewhere on the board
GP7: J5.14; also elsewhere on the board
LINEL: C24.1; also elsewhere on the board
LINER: C25.1; also elsewhere on the board
MIC: C28.1; also elsewhere on the board
MONO_IN: C46.2; also elsewhere on the board
unnamed: C22.2, R11.1, R12.1
unnamed: C23.2, R10.1, R13.1
unnamed: C24.2, R14.2, R15.1
unnamed: C25.2, R21.2, R22.1
unnamed: C46.1, R35.2, R36.1
unnamed: CT12.1, R24.2, R25.1
unnamed: C53.1, J5.12, R37.2
unnamed: J5.13, RP2.6 (R3.2)
unnamed: C56.1, J5.15, R40.2
unnamed: J5.11 (P111), RP2.8 (R1.2)
unnamed: CT10.2, J2.T, J7.1, R8.2
unnamed: CT3.2, J2.R, J7.4, R9.1
unnamed: C26.1, J3.T, J8.1, R15.2
unnamed: C27.1, J3.R, J8.4, R22.2
unnamed: C58.1, J10.1, J11.3, R12.2
unnamed: C59.1, J10.4, J11.1, R10.2
unnamed: C28.2, C29.1, J4.T, J9.1, J13.1, R25.2
unnamed: J13.4, R36.2
unnamed: JP2.2, U7.1 (IN0)
unnamed: J5.3, RP2.7 (R2.2)
unnamed: J5.6, RP2.5 (R4.2)
unnamed: R23.2, U7.7 (OUT1)
unnamed: R26.2, U7.6 (OUT2)
unnamed: C31.2, U7.5 (VCAP)
OUTPUT_L: CT10.1; also elsewhere on the board
OUTPUT_R: CT3.1; also elsewhere on the board
RXD: R40.1; also elsewhere on the board
SJ3_1: U7.3 (IN2); also elsewhere on the board
SJ3_3: C34.2, R26.1; also elsewhere on the board
SJ4_1: U7.2 (IN1); also elsewhere on the board
SJ4_3: C32.2, R23.1; also elsewhere on the board
TXD: R37.1; also elsewhere on the board
~CDCS0: CN1.37; also elsewhere on the board
~CDCS1: CN1.38; also elsewhere on the board
~IOCS16: CN1.32; also elsewhere on the board
~IOR: CN1.25; also elsewhere on the board
~IOW: CN1.23; also elsewhere on the board
~RESET: CN1.1; also elsewhere on the board

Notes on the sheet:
This should be some sort of mute switch.

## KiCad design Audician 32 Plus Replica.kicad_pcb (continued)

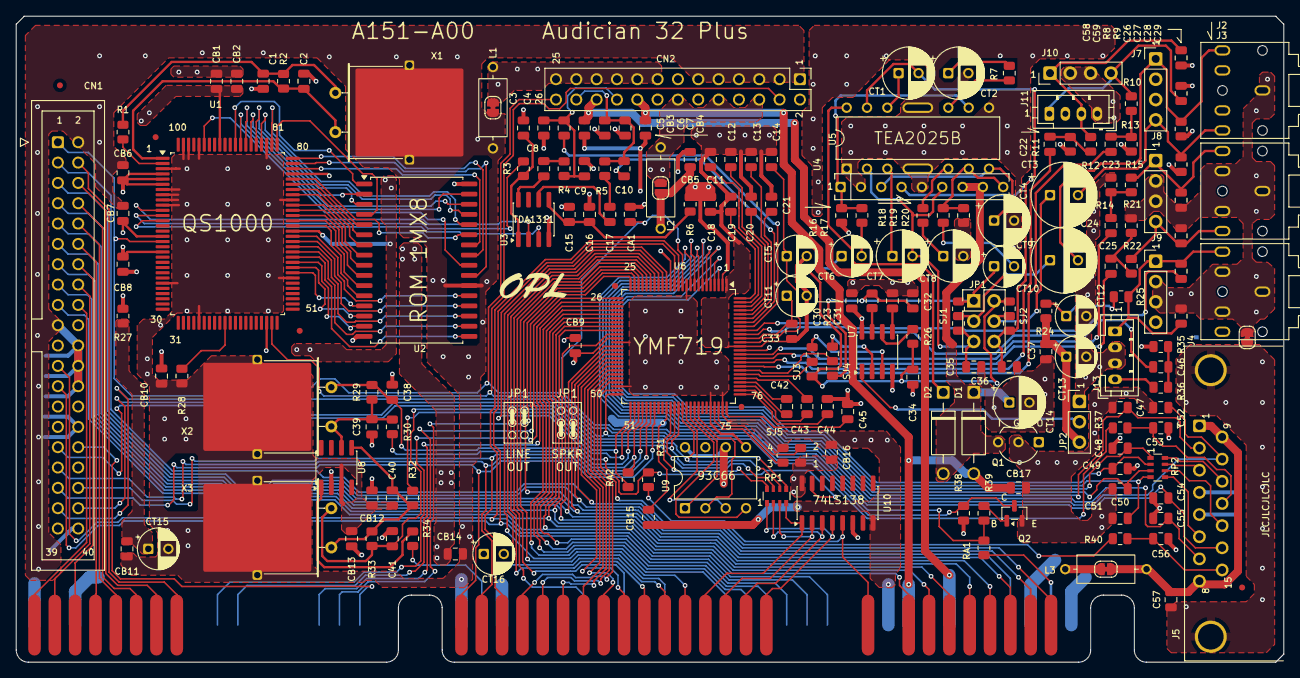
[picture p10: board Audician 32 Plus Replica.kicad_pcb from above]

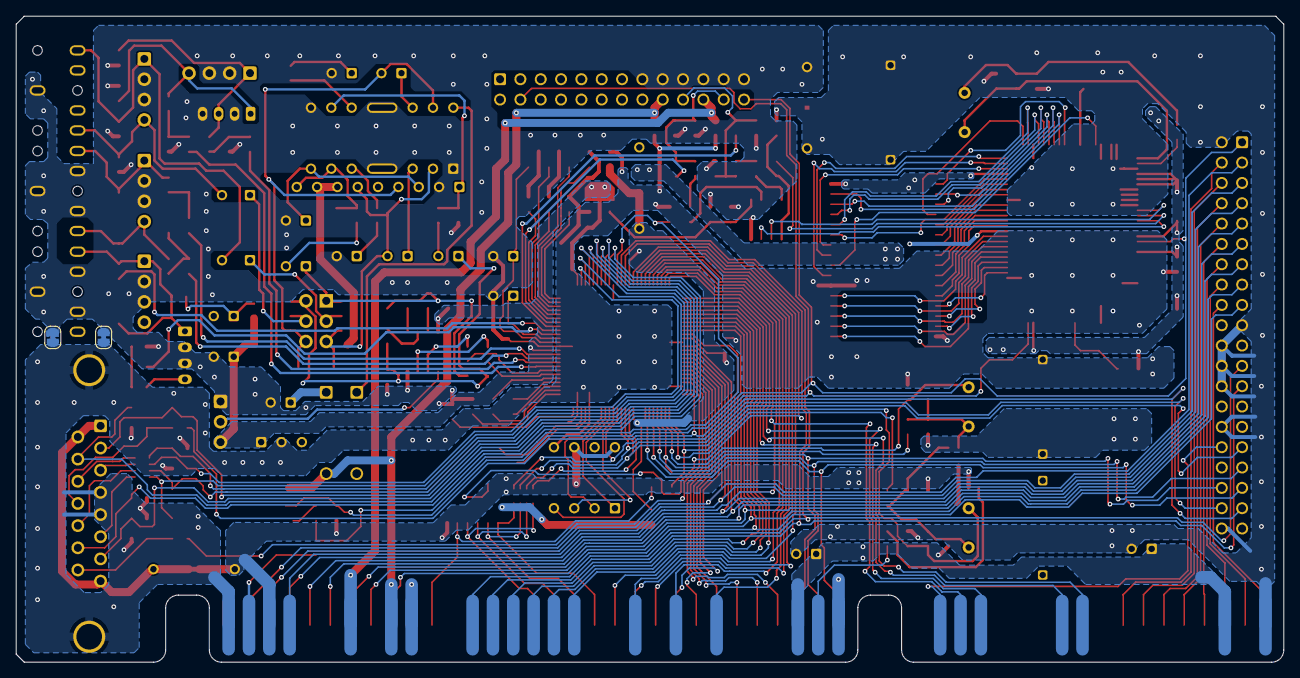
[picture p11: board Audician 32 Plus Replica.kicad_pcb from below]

Board: 2 copper layers, 158.4 x 80.7 mm, 189 parts (2 on the bottom side), 203 nets.

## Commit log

2026-07-30 Optimize routing
    [Audician 32 Plus Replica-B_Cu.gbr, Audician 32 Plus Replica-B_Mask.gbr, Audician 32 Plus Replica-B_Paste.gbr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]
2026-07-31 Update BOM
    [Audician 32 Plus Replica-CuBottom.gbr, Audician 32 Plus Replica-CuTop.gbr, Audician 32 Plus Replica-EdgeCuts.gbr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]
2026-07-31 Add PDF schematic and render
2026-07-31 Add EEPROM with no CDROM
    [Audician 32 Plus Replica.kicad_sch]
2026-08-02 Fix BOM Error
    [Amplifier.kicad_sch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]
2026-08-04 Add notes to schematic
    [Amplifier.kicad_sch, Audician 32 Plus Replica.kicad_sch, Connectors.kicad_sch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]
